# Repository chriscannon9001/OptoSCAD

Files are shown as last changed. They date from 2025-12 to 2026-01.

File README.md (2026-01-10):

# OptoSCAD
Parametric 3d Printable Opto-mechanics.

Plastic is always going to be second-rate for opto-mech, but it actually can do many jobs so long it's not expected to carry a heavy load, or meet interferometer precision.

This project is about opto-mech as fast and cheap as it can reasonably be.

## Installation

Install OpenSCAD, find your libraries folder.

Clone OptoSCAD from git into the libraries folder. Same goes for NopSCADlib (dependency) [https://github.com/nophead/NopSCADlib](https://github.com/nophead/NopSCADlib).

## Hardware Requirements

* 3d Printer
* stock of screws and nuts (e.g. M3, M4, M6)
* stock of springs (e.g. 6x20x.4 mm and 8x20x.8mm)
* (optional) chop saw
* (optional) metal stock, e.g. 6mm dia (for cages) and 12.7mm dia rod or tubes (for posts) 
* (optional) drill press and taps, i.e. if you want to thread solid rod posts (not required)

## Getting started

The folder OptoSCAD/render has some example .stl files you can open in CAD or a slicer just to get a feel for some of the common variants.

See below under Project status to find links to Thingiverse, which offers 3d views of the same rendered .stl files.

Load customizer from OpenSCAD/cust/*.scad to start customizing a design.

***Catalog of (mostly) working mechanics:***

| Customizer |Post|Cage| Notes | Offsite Link |
|---|----|----|---|---|
| cust/Adapter Plates.scad | | | | |
| cust/Adapter Right Angle.scad | | | | |
| cust/Post Holders.scad | X | | untested| [thingiverse](https://www.thingiverse.com/thing:7243131) |
| cust/Post Right Angle Clamp.scad| X | | untested | |
| cust/Cage Plate.scad | X | X | needs work | [thingiverse](https://www.thingiverse.com/thing:7243140) |
| cust/Mirror Mount.scad | X | X | also on HeNe | [thingiverse](https://www.thingiverse.com/thing:7243140) |
| cust/Lens Mount, Focal.scad | | X | untested | |
| cust/Lens Mount, XY.scad | | | in planning | |
| cust/Integrating Sphere.scad | | | unreleased; coming soon | |

## Filaments

***Ranked by creep:***

* PLA (worst)
* PETG
* ASA, ABS
* PC (best)

Coincidentally or not, that's the same as sorting by increasing glass transition temperature Tg.

(Where does PA belong, perhaps between PETG and ASA?)

Some say composite filaments are more stable but my impression is the effect of filament filler is rather weak; PA-CF has higher creep and is also softer than PC.

## Project Status

Bringing every form of opto-mech into the project would be a little ambitious.

I'm working on plans for test beds for benchmarks.

***Planned :***

* Lens Mount
* Integrating Sphere
* Robotics

## Hardware Library

There are other hardware libraries out there already, but OptoSCAD includes its own hardware library. Why do that? OptoSCAD's internal hw lib is aimed at forming negatives (pockets) for trapping nuts, counterboring screws (on the low level side) and forming screw/spring adjuster sets and other things (on the high level side), all with 3d printing in mind. Other libraries are more low-level.

Here is a brief demo snippet.

```
include <OptoSCAD/hw.scad>

$fa=2;
$fs=.2;

// SHC and hex nut with pockets
translate([0, -7, 0]) {
    %neg_hex("M3", 1.0, sink=5, capture=true, minor_access=5);
    vit_hex("M3", 1, TLshaft=8);
}
translate([0, -7, -6]) rotate([180, 0, 0]) {
    %neg_boreSHC("M3", 1.0, sink=3);
    vit_SHC("M3", 1);
}

// spring/screw adjuster with SHC and hex nut
// springspec - ["name", OD, wire, free-length, N-coils, isclosed, isflat, 2nd-OD, color]
spring = ["6x20", 6, .4, 20, 12, 1, 0, 0, "red"];
translate([0, 7, 0]) {
    %neg_adjuster_screwnutspring("M3", spring, l_compressed=6, washer=true, typehead=0, typenut=2, overhead=4);
    vit_adjuster_screwnutspring("M3", spring, l_compressed=6, washer=true, typehead=0, typenut=2);
}
```

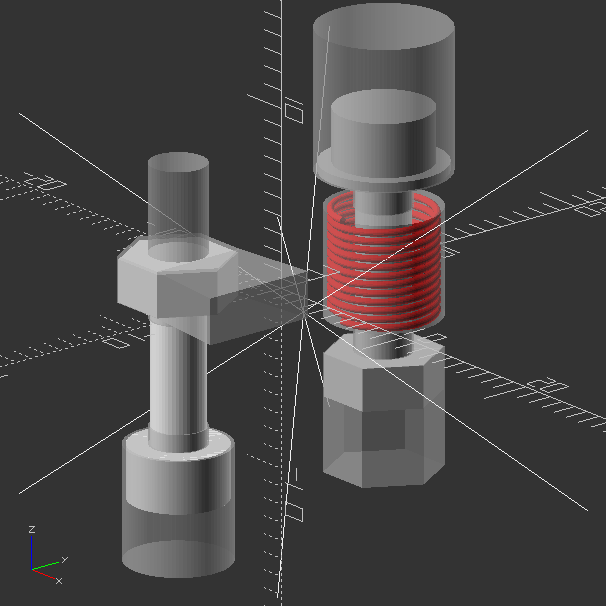
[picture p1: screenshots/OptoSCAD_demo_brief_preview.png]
OptoSCAD demo_brief preview


### More hardware lib demo

Goto the folder OptoSCAD/demo and open of the demo files in OpenSCAD to see demonstrations in more detail. The files hw_pockets.scad and hw_features.scad and hwlookup.scad have additional usage documentation inline.

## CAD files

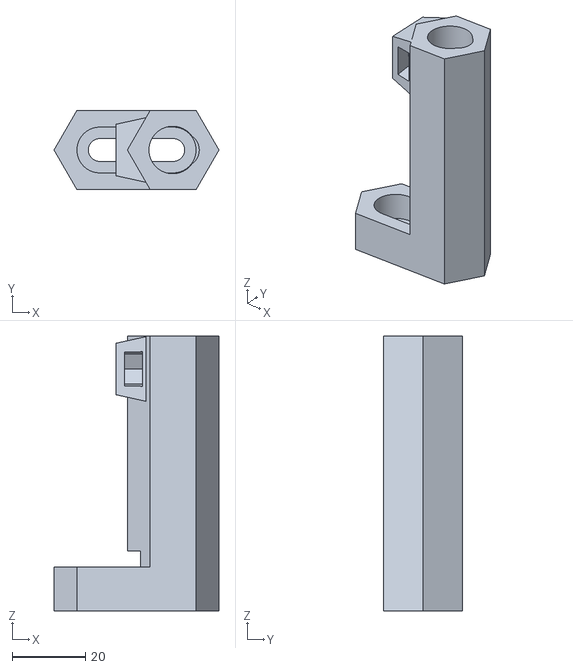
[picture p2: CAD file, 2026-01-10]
render/Post Holders - hexedM6h75id12.7cam20.stl
45.0 x 21.7 x 75.0

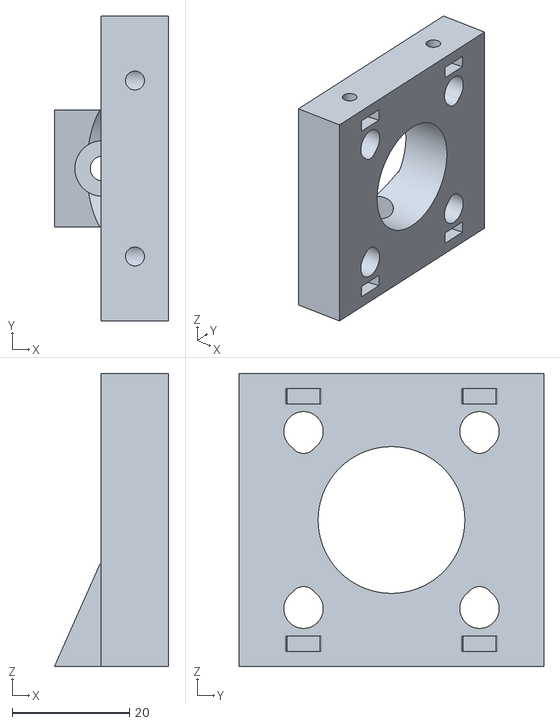
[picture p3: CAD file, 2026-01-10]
render/Cage Plate - cage6x30baseM4.stl
19.5 x 52.0 x 50.0

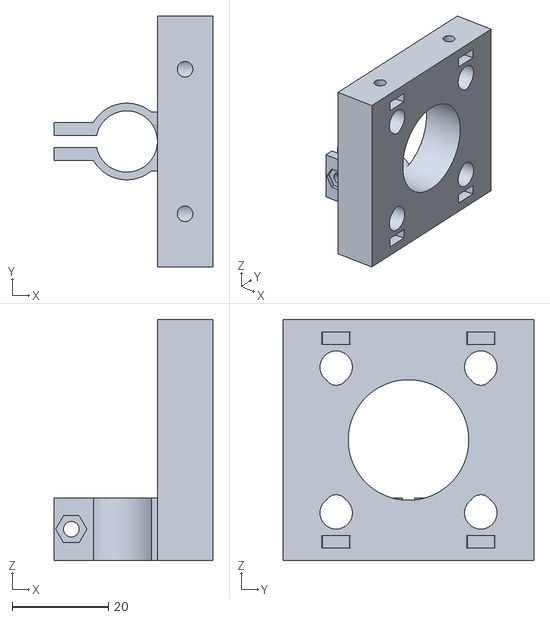
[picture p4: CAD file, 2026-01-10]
render/Cage Plate - cage6x30clamp12.7.stl
32.9 x 52.0 x 50.0

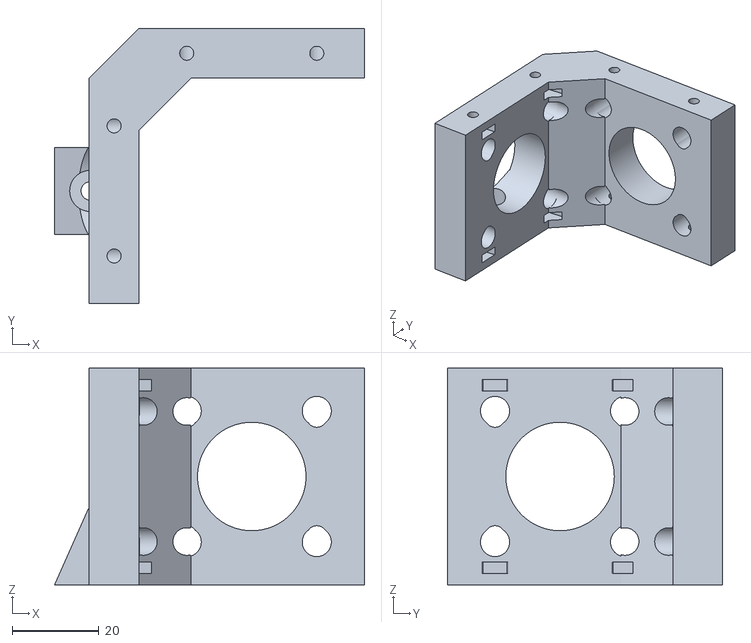
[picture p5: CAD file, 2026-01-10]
render/Cage Plate - cage6x30right90baseM4.stl
71.5 x 63.5 x 50.0

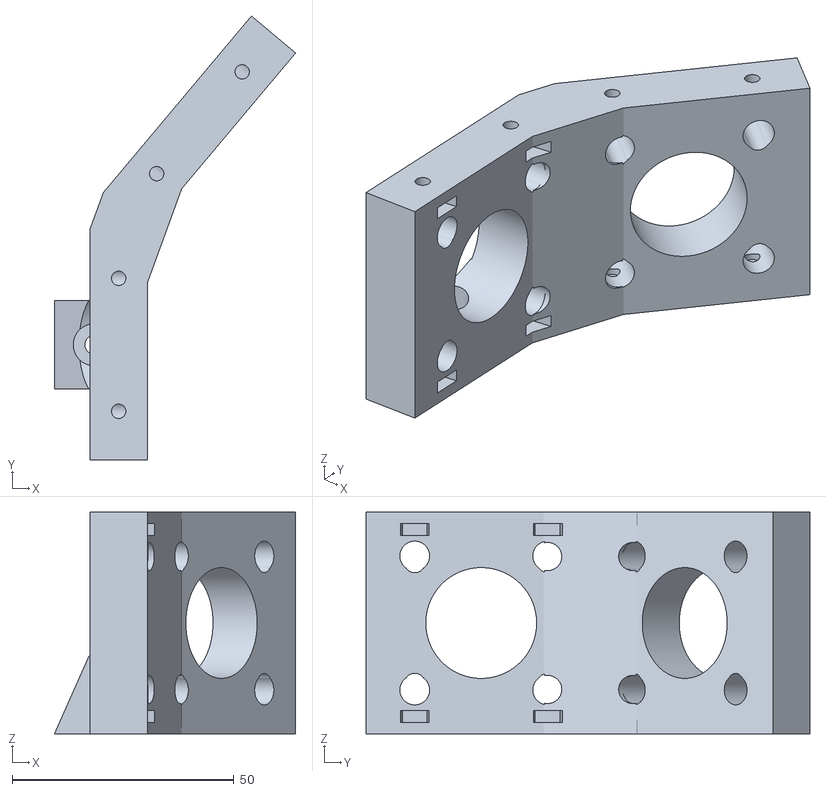
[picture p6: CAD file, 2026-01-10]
render/Cage Plate - cage6x30right140baseM4.stl
54.4 x 100.2 x 50.0

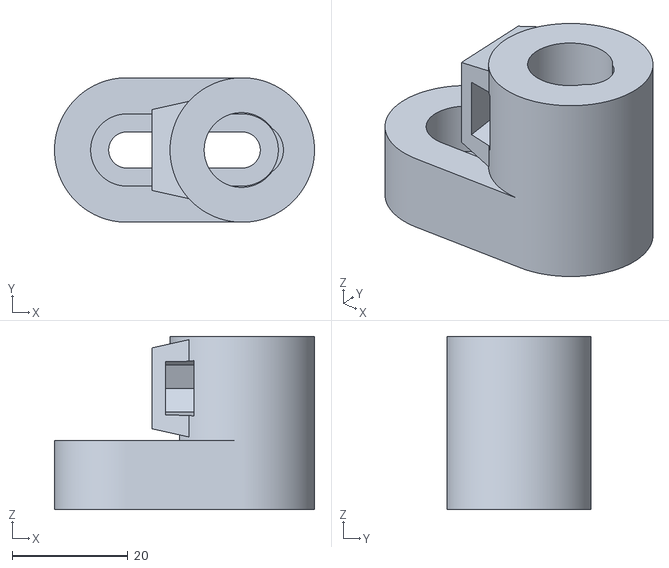
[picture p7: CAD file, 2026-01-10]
render/Post Holders - M6h30id12.7cam20.stl
45.0 x 25.0 x 30.0

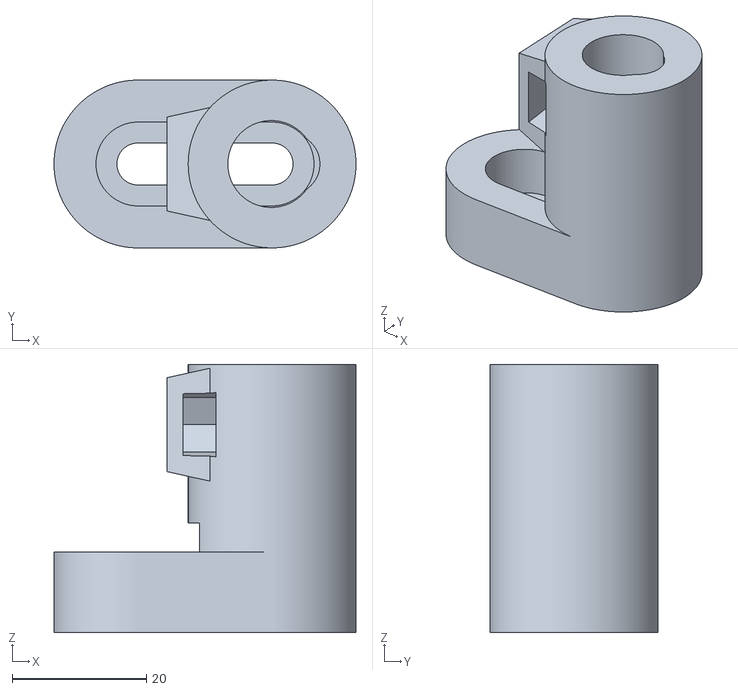
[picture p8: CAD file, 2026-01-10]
render/Post Holders - M6h40id12.7cam20.stl
45.0 x 25.0 x 40.0

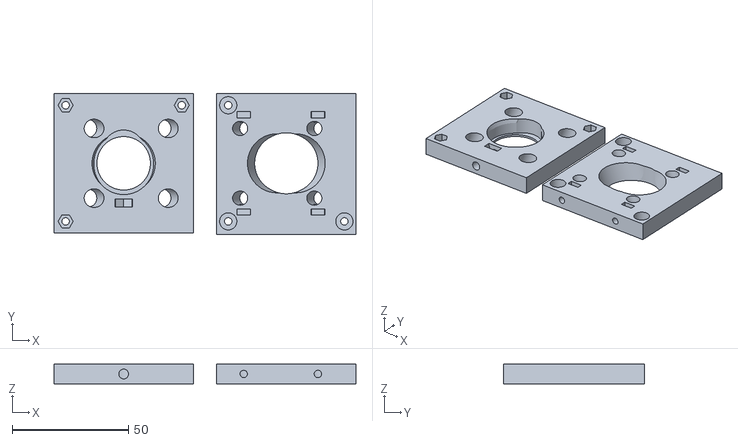
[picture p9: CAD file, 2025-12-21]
render/Mirror Mount - plate60id25.4spring6x20cage6x30aoi20.stl
130.0 x 60.6 x 8.50

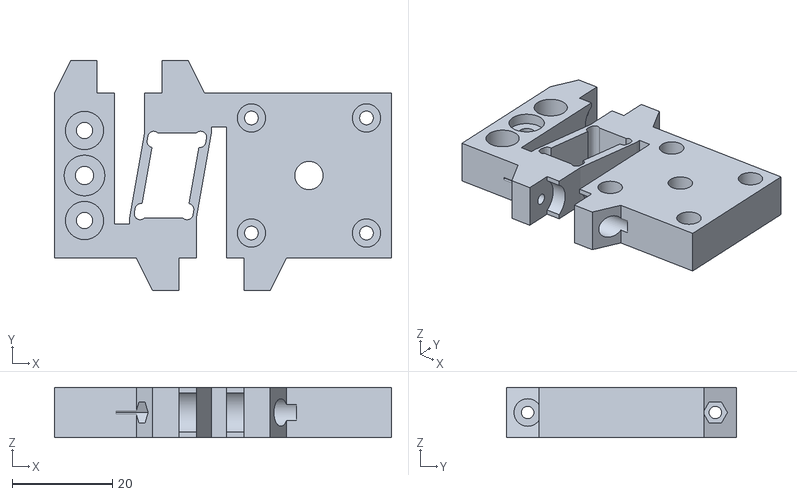
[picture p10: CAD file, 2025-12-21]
render/stepactuator_h10mm_NEMA11_M3.stl
67.4 x 46.0 x 10.0

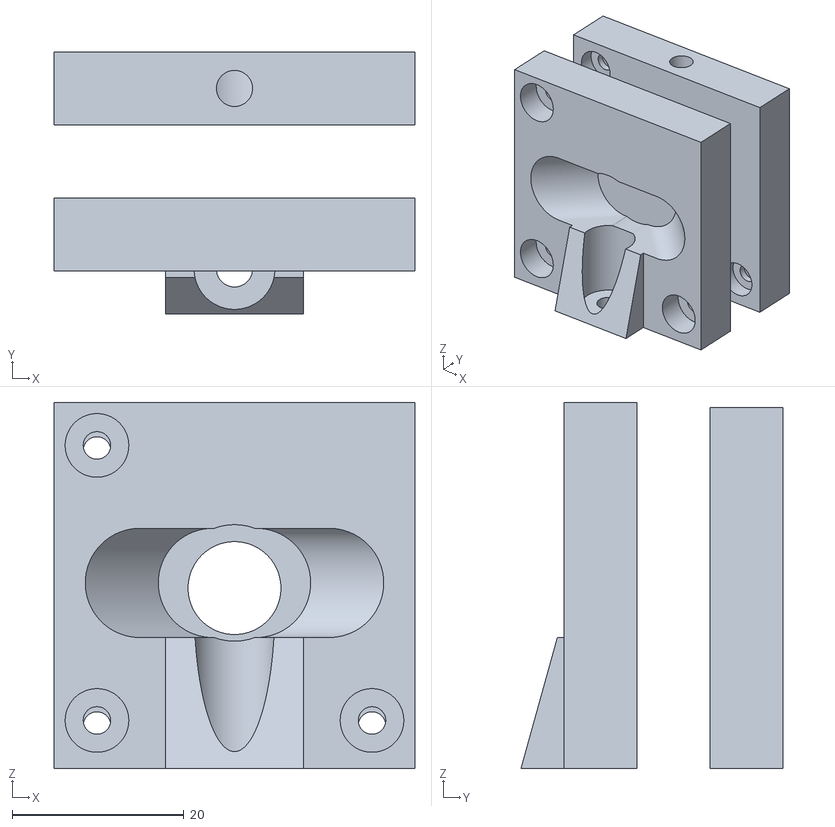
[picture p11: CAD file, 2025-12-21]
render/Mirror Mount - leftplate42id12.7spring6x20baseM4.stl
42.0 x 30.5 x 42.6

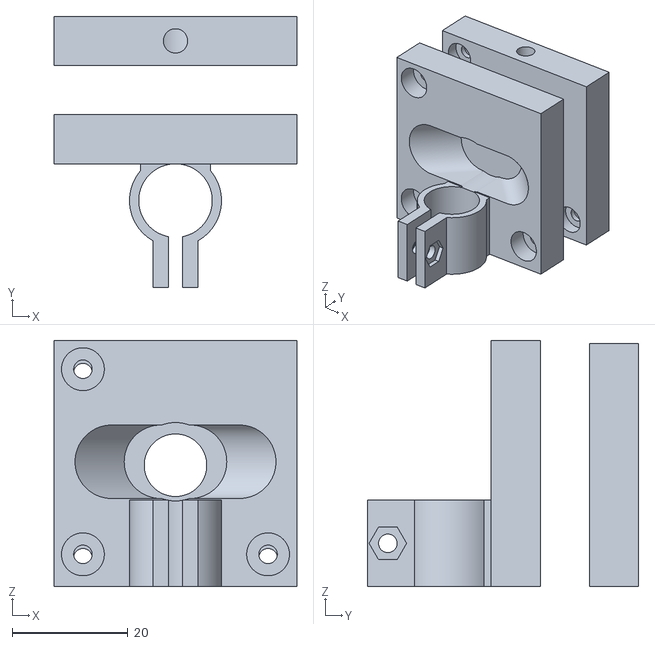
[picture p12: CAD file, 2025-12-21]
render/Mirror Mount - leftplate42id12.7spring6x20clamp12.7.stl
42.0 x 46.9 x 42.6

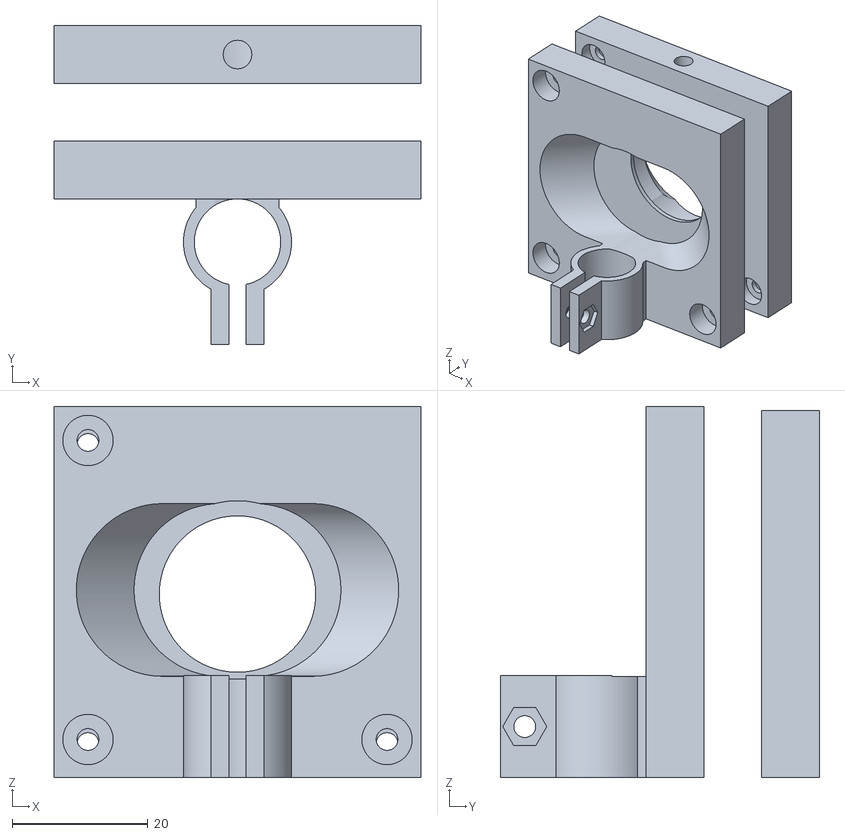
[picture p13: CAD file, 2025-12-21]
render/Mirror Mount - leftplate52id25.4spring6x20clamp12.7.stl
54.0 x 46.9 x 54.6

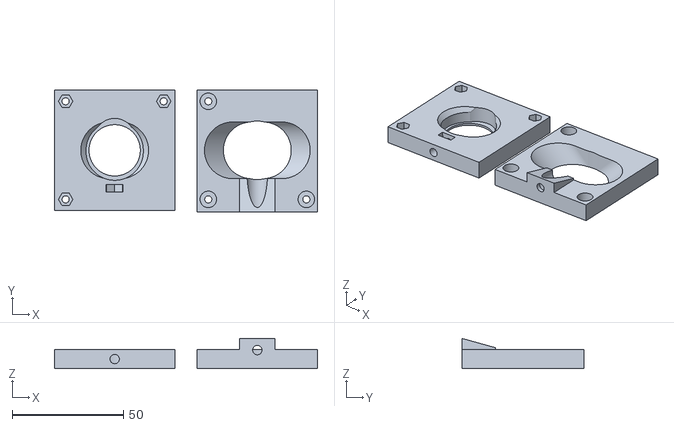
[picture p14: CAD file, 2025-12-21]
render/Mirror Mount - leftplate52id25.4spring6x20baseM4.stl
118.0 x 54.6 x 13.5

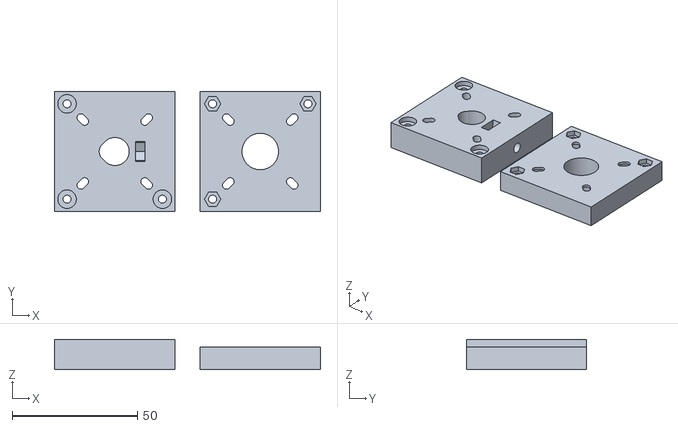
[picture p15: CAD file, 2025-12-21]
render/Mirror Mount, HeNe to 11odcollimator.stl
106.0 x 48.0 x 12.0

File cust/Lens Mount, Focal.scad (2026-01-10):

/* 'Lens Mount, Focal'
 * A lens mount with precision focal adjuster.
 *
 * Authors:
 * Chris Cannon
 */

use <../hw_pockets.scad>
use <../hw_features.scad>
use <../flexure.scad>

vitamins = true;

// [snug, close, loose, gap]
margins = [.06, .12, .24, .35];

/* [Cage Plate] */

Cage_setscrew = "M3";

Cage_nuttype = 2; //[2: hex, 3: square, 4: tapped]

D_plate1 = 44;

L_plate1 = 50;

T_plate1 = 11.5;

// [rod, oncenter, AOI]
Cage_rods = [6.35, 30, 0];

/* [Mirror Plate] */

D_plate2 = 20;

L_plate2 = 30;

T_plate2 = 9.5;

// Mirror diameter, mm
Diameter = 12.7;

// Mirror diameter tolerance +/-, mm
Dia_tol = .3;

// Inner-diameter, thickness of flange, mm
Flange = [10.8, 1];

// Size of setscrew
Setscrew_size = "M4";

Setscrew_type = 2; //[2: hex, 3: square, 4: tapped]

// Offset (mm) from mirror opening to nut for setscrew
Setscrew_nutoffset = 2.5;

// rotation around y-axis where setscrew is attached
Setscrew_position = 90;

/* [Flexure] */

// [Length, Width, Depth, Gap]
Flex = [22, 16, 12, 2.9];

// total length of flex
L_flexTL = 36;

rh_flex = true;

/* [Actuator] */
Screw_dz = "M3";

Supportthick_dz = 3;

Nuttype_dz = 2; //[2: hex, 3: square, 4: tapped]

// springspec - ["name", OD, wire, free-length, N-coils, isclosed, isflat, 2nd-OD, color]
Spring_spec = ["8x20", 8, .8, 20, 4.8, 1, 0, 0, "red"];

compressedLength = 10;

Actuator_inset = 5;

module _end_cust_() {}

$fa = $preview? 5 : 1;
$fs = $preview? .4 : .1;

span = Flex[1] + 2*Flex[3];
s = rh_flex? 1 : -1;

module coord_actuator() {
    x = (span - compressedLength) / 2;
    y = -L_plate1/2 + Actuator_inset;
    z = Flex[2]/2;
    translate([x, s*y, z])
    rotate([0, 90, 0])
    rotate(-s*90)
    children();
}

difference() {
    union() {
        // plate1
        translate([span/2+T_plate1/2, 0])
        linear_extrude(D_plate1+Flex[2])
        square([T_plate1, L_plate1], center=true);
        // plate2
        D2 = D_plate1/2+D_plate2/2;
        translate([-span/2-T_plate2/2, 0]) {
            linear_extrude(D2+Flex[2])
            square([T_plate2, L_plate2], center=true);
            // plate2b
            linear_extrude(Flex[2])
            square([T_plate2, L_plate1], center=true);
        }
        // backing for the adjuster
        linear_extrude(Flex[2])
        polygon([[-span/2, -s*L_plate1/2],
            [span/2-compressedLength, -s*L_plate1/2],
            [span/2-compressedLength, -s*L_flexTL/2],
            [-span/2, -s*L_flexTL/2]]);
        // flexure
        thick3 = (L_flexTL - Flex[0])/2;
        flexure_translation1(Flex[0], Flex[1], Flex[2], thick1=0.8, thick2=2, thick3=thick3, bias=0);
        // connect flexure across the gap
        for (j = [-1,1]) {
            y = j*s*(Flex[0]/2+thick3/2+.25);
            x = j*(Flex[1]/2+Flex[3]/2);
            translate([x, y])
            linear_extrude(Flex[2])
            square([Flex[3], thick3-.5], center=true);
        }
    }
    // mirror cutout
    diag = sqrt(D_plate2^2+L_plate2^2);
    translate([-span/2, 0, D_plate1/2+Flex[2]])
    rotate([0, -90, 0])
    neg_shaftsetscrew(diag, T_plate2, Diameter, Dia_tol, Flange, Setscrew_size, Setscrew_type, Setscrew_nutoffset, Setscrew_position, margins=margins);
    // cage rod pockets
    translate([span/2+T_plate1+.05, 0, D_plate1/2+Flex[2]])
    rotate([0, -90, 0]) {
        rad_ss = (D_plate1 - Cage_rods[1])/2 + 1;
        neg_cage1(Cage_rods[0], Cage_rods[1], T_plate1+.1, Cage_setscrew, rad_ss, ss_angle=-1,  ss_nut_type=Cage_nuttype, AOI=Cage_rods[2], margins=margins, fast=$preview, overhead=span+T_plate2, overbore=2*margins[3]);
        cylinder(h=T_plate1+.1, d=Diameter);
    }
    // actuator pockets
    coord_actuator()
    neg_adjuster_screwnutspring(Screw_dz, Spring_spec, typehead=0, typenut=Nuttype_dz, washer=true, l_compressed=compressedLength, support_thick=Supportthick_dz, access_length=10, overhead=10, margins=margins);
}

if (vitamins) {
    coord_actuator()
    vit_adjuster_screwnutspring(Screw_dz, Spring_spec, typehead=0, typenut=2, washer=true,  l_compressed=compressedLength, support_thick=Supportthick_dz);
}

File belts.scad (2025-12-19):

// Terminology:
// L - distance between pulley centers
// Cb - total Circumference of belt
// d1, d2 - diameters of pulleys
// C1, C2 - Circumferences of pulleys
// pitch - pitch from tooth to tooth
// Tb - number of teeth of belt
// T1, T2 - number of teeth of pulleys
// alpha - angle (degrees)
// beltspec - [L, pitch, Tb, T1, T2, alpha]

// an intermediate
function d0(Cb, d1, d2) = 4*Cb-2*PI*(d1+d2);

// lower level - returns the distance between pulley axles
function L_pulley_d0(d0, d1, d2) = (d0 + sqrt(d0^2 - 32*(d1-d2)^2))/16;

// returns L, the distance between pulleys
function L_pulley(Cb, d1, d2) = L_pulley_d0(d0(Cb, d1, d2), d1, d2);

// return Cb, the length of the belt
function Cb_pulley(L, d1, d2) = 2*L + PI*(d1+d2)/2 + (d1-d2)^2/(4*L);

function alpha(L, d1, d2) = asin((d1-d2)/L/2);

// round a up to the nearest mod
function next_up(a, mod) = mod*ceil(a/mod);

function Tb_nearest_belt(T1, T2, L, pitch, nearest=2) = next_up(Cb_pulley(L/pitch, T1/PI, T2/PI), nearest);

// beltspec - [L, pitch, Tb, T1, T2, alpha]
function beltspec1(T1, T2, L, pitch) = [L, pitch, Cb_pulley(L, T1/PI, T2/PI)/pitch, T1, T2, alpha(L/pitch, T1/PI, T2/PI)];

function beltspec2(T1, T2, Tb, pitch) = [pitch*L_pulley(Tb, T1/PI, T2/PI), pitch, Tb, T1, T2, alpha(L_pulley(Tb, T1/PI, T2/PI), T1/PI, T2/PI)];

// returns beltspec with Tb rounded up and L to match
function beltspec_nearest(T1, T2, L, pitch, nearest=2) = beltspec2(T1, T2, Tb_nearest_belt(T1, T2, L, pitch, nearest=nearest), pitch);

// similar to circle, but limits angular extent between a1 to a2 (degrees)
module arc(r, a1, a2) {
    del_a = abs(a2 - a1);
    // points carries a triangle wedge with a low polygon circle between arms
    points = [[0,0], for (i=[0:6]) [r*1.5*cos(a1 + i*del_a/6),r*1.5*sin(a1 + i*del_a/6)]];
    intersection() {
        polygon(points);
        circle(r);
    }
}

// form a 2d sketch of the belt
module belt_2d(beltspec, thick) {
    L = beltspec[0];
    pitch = beltspec[1];
    Tb = beltspec[2];
    T1 = beltspec[3];
    T2 = beltspec[4];
    alpha = beltspec[5];
    r1 = T1*pitch/PI/2;
    r2 = T2*pitch/PI/2;
    a11 = 90-alpha;
    a12 = 270+alpha;
    a21 = -90+alpha;
    a22 = 90-alpha;
    d = sqrt(L^2 - (r2-r1)^2);
    // belt around gear1
    difference() {
        arc(r1+thick, 90-alpha, 270+alpha);
        circle(r1);
    }
    // belt around pulley2
    translate([L, 0, 0]) difference() {
        arc(r2+thick, -90+alpha, 90-alpha);
        circle(r2);
    }
    // belt along top straight
    x = r1*cos(a11);
    y = r1*sin(a11);
    translate([x, y, 0]) rotate([0, 0, -alpha]) square([d, thick]);
    // belt along bottom straight
    x2 = (r1+thick)*cos(a12);
    y2 = (r1+thick)*sin(a12);
    translate([x2, y2, 0]) rotate([0, 0, alpha]) square([d, thick]);
}

// a little demo
spec = beltspec_nearest(50, 20, 35, 2, nearest=2);
echo(spec);
linear_extrude(6) belt_2d(spec, 2);

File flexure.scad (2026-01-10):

//use <./hw_mates.scad>
use <./hw_features.scad>
use <./util.scad>

module slot(h, r, x1, y1, x2, y2) {
    hull() {
        translate([x1, y1, 0]) cylinder(h=h, r=r);
        translate([x2, y2, 0]) cylinder(h=h, r=r);
    }
}

module flexure_rotation1(length, width, height, n_spans, uncut_length=2, thick=0.8, vgap=0.2, fillet=0.4) {
    // flexure_rotation1 is a pair of webs that span front and
    // back plates. From the top, the cross-section of the webs
    // is an X, but the spans of the two webs don't intersect.
    // This is a classic rotation flexure, with high stiffness
    // the other 5 axes.
    // Coordinates w.r.t. center bottom, as with cylinder module
    //
    // length: mm, gap in y between front, back plates
    // width: mm, width in x of front, back plates
    // height: mm, height in z of module
    // n_spans: int, number of spans per web from plate to plate
    // uncut_length: mm, each web needs an amount of diag length not cut into spans
    // thick: mm, default 0.8, thickness of spans, normally 2x nozzle diameter
    // vgap: mm, default 0.2, need a gap between spans so they don't fuse
    // fillet: mm, radius of fillet on inside corner of spans
    length2 = length + thick/1.414;
    width2 = width - thick/1.414;
    theta = atan(length2/width2);
    diag = sqrt(length2^2 + width2^2);
    cut_len = diag - uncut_length*2;
    dy = height/(n_spans*2);
    // front and back bases
    translate([0, length/2+thick/2, height/2])
        cube([width, thick, height], center=true);
    translate([0, -length/2-thick/2, height/2])
        cube([width, thick, height], center=true);
    // even flexes
    rotate([0, 0, theta])
        difference() {
            translate([0, 0, height/2]) cube([diag, thick, height], center=true);
            for (i = [1:n_spans]) {
                y = dy * (i * 2 -.5);
                translate([0, 0, y]) cube([cut_len, thick+1, dy+vgap*2], center=true);
            }
        }
    // odd flexes
    rotate([0, 0, -theta])
        difference() {
            translate([0, 0, height/2]) cube([diag, thick, height], center=true);
            for (i = [1:n_spans+.5]) {
                y = dy * (i * 2 - 1.5);
                translate([0, 0, y]) cube([cut_len, thick+1, dy+vgap*2], center=true);
            }
        }
    // fillet
    angle = theta/2;
    y = length/2;
    x = width/2 - thick/sin(theta);
    translate([x, y, 0]) rotate([0, 0, angle])
        filletsingle(fillet, height, angle=angle*2);
    translate([-x, y, 0]) rotate([0, 0, 180-angle])
        filletsingle(fillet, height, angle=angle*2);
    translate([x, -y, 0]) rotate([0, 0, -angle])
        filletsingle(fillet, height, angle=angle*2);
    translate([-x, -y, 0]) rotate([0, 0, 180+angle])
        filletsingle(fillet, height, angle=angle*2);
}

module flexure_rotation2(length, width, height, n_spans, uncut_length=2, thick=0.8, vgap=0.2, fillet=0.4) {
    length2 = length + thick/1.414;
    width2 = width - thick/1.414;
    theta = atan(length2/width2);
    diag = sqrt(length2^2 + width2^2);
    cut_len = diag - uncut_length*2;
    dy = height/(n_spans*2);
    // front and back bases
    translate([0, length/2+thick/2, height/2])
        cube([width, thick, height], center=true);
    translate([0, -length/2-thick/2, height/2])
        cube([width, thick, height], center=true);
}

module flexure_translation1(length, width, height, thick1=0.8, thick2=2, thick3=5, bias=0) {
    // flexure_translation1 is the simplest 2-leaf translation flexure
    // This is a classic translation flexure, with high stiffness
    // the other 5 axes.
    // coordinates w.r.t. center bottom, as with cylinder module
    //
    // length: mm, gap in y between front, back plates
    // width: mm, width in x of front, back plates
    // height: mm, height in z of module
    // thick1: mm, default 0.8, thickness of leafs at their thinnest, normally 2x nozzle diameter
    // thick2: mm, default 2, thickness of leafs at their max
    // thick3: mm, default 5, thickness of ground, floating bases
    // bias: mm, default 0, top and bottom are shifted by this amount (clockwise)
    radius = thick2 - thick1;
    slope = 2*bias/length;
    difference() {
        union() {
            // bottom base
            translate([-width/2-bias, -length/2-thick3, 0]) cube([width, thick3, height]);
            // top base
            translate([-width/2+bias, length/2, 0]) cube([width, thick3, height]);
            // left side with slope (bias)
            translate([-width/2, 0, 0]) linear_extrude(height) polygon([[-bias, -length/2], [thick2-bias, -length/2], [thick2+bias, length/2], [bias, length/2]]);
            // right side with slope (bias)
            translate([width/2, 0, 0]) linear_extrude(height) polygon([[-bias, -length/2], [-thick2-bias, -length/2], [-thick2+bias, length/2], [bias, length/2]]);
        }
        dl = 1.1*thick1;
        for (s = [-1, 1]) {
            y1 = s*(.7*radius - length/2);
            y2 = y1 + s*dl;
            dx1 = y1 * slope;
            dx2 = y2 * slope;
            translate([0, 0, -.001]) slot(height+.002, radius, dx1-width/2+thick2, y1, dx2-width/2+thick2, y2);
            translate([0, 0, -.001]) slot(height+.002, radius, dx1+width/2-thick2, y1, dx2+width/2-thick2, y2);
        }
    }
}

module flexure_translation2(length, width, height, gap1=2, gap2=1, thick1=0.8, thick2=2., thick3=5) {
    // flexure_translation2 is a 4-leaf translation flexure
    // This is a classic translation flexure, with high stiffness
    // the other 5 axes.
    // Coordinates are w.r.t. the floating base
    //
    // length: mm, gap in y between front, back plates
    // width: mm, width in x of front, back plates
    // height: mm, height in z of module
    // gap1: mm, gap allowing movement
    // gap2: mm, air gap between floating and ground
    // thick1: mm, default 0.8, thickness of leafs at their thinnest, normally 2x nozzle diameter
    // thick2: mm, default 2, thickness of leafs at their max
    // thick3: mm, default 6, thickness of ground, floating bases
    radius = thick2 - thick1;
    width_g = width - 2*(thick1 + radius*2 + gap1);
    length2 = length - thick3 - gap2;
    difference() {
        union() {
            // ground platform
            translate([-width_g/2, -thick3, 0]) cube([width_g, thick3, height]);
            // moving platform
            translate([-width/2, -thick3*2-gap2, 0]) cube([width, thick3, height]);
            // floating platform
            translate([-width/2, length2, 0]) cube([width, thick3, height]);
            // leafs
            translate([(width-thick2)/2, (length2-thick3-gap2)/2, height/2]) cube([thick2, length, height], center=true);
            translate([-(width-thick2)/2, (length2-thick3-gap2)/2, height/2]) cube([thick2, length, height], center=true);
            translate([-(width_g-thick2)/2, length2/2, height/2]) cube([thick2, length2, height], center=true);
            translate([(width_g-thick2)/2, length2/2, height/2]) cube([thick2, length2, height], center=true);
            // fillets
            translate([width_g/2, length2, -.001]) rotate([0, 0, 135]) filletsingle(radius, height+.002, angle=90);
            translate([-width_g/2, length2, -.001]) rotate([0, 0, 45]) filletsingle(radius, height+.002, angle=90);
        }
        // remove cylinders to make flex lines
        translate([-width_g/2+radius+thick1, 0, -.001]) cylinder(h=height+.002, r=radius);
        translate([width_g/2-radius-thick1, 0, -.001]) cylinder(h=height+.002, r=radius);
        translate([-width/2+radius+thick1, 0, -.001]) cylinder(h=height+.002, r=radius);
        translate([width/2-radius-thick1, 0, -.001]) cylinder(h=height+.002, r=radius);
        translate([-width_g/2+radius+thick1, length2-radius, -.001]) cylinder(h=height+.002, r=radius);
        translate([width_g/2-radius-thick1, length2-radius, -.001]) cylinder(h=height+.002, r=radius);
        translate([width/2-radius-thick1, length2-radius, -.001]) cylinder(h=height+.002, r=radius);
        translate([-width/2+radius+thick1, length2-radius, -.001]) cylinder(h=height+.002, r=radius);
    }
}

module adjuster_alongside_neg(screwsize, springspec, H, W, l_compressed, support_thick=2, decenter=0) {
    translate([0, W/2+decenter, H/2]) rotate([0, 90, 0]) rotate([0, 0, 90]) neg_adjuster_screwnutspring(screwsize, springspec, l_compressed=l_compressed, support_thick=support_thick, overhead=W+support_thick);
}

module adjuster_alongside(screwsize, springspec, H, W, l_compressed, support_thick=2, decenter=0) {
    x1 = l_compressed/2;
    x2 = x1 + support_thick + W/2;
    x3 = x2 + W/2;
    difference() {
        union() for (s = [-1, 1]) {
            linear_extrude(H) polygon([[s*x1, 0], [s*x1, W], [s*x2, W], [s*x3, 0]]);
        }
        adjuster_alongside_neg(screwsize, springspec, H, W, l_compressed, support_thick=support_thick, decenter=decenter);
    }
}
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

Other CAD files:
render/Mirror Mount - plate60id25.4spring6x20cage6x30aoi0.stl
hw.scad
cust/Adapter Plates.scad
cust/Adapter Right Angle.scad
cust/Cage Plate.scad
cust/Mirror Mount.scad
cust/Post Holders.scad
cust/Post Right Angle Clamp.scad
cust/Pulley Maker.scad
demo/demo_brief.scad
demo/demo_hw_features.scad
demo/demo_hw_pockets.scad
demo/demo_hw_pockets_old.scad
hw_features.scad
hw_pockets.scad
hwlookup.scad
pulleys.scad
util.scad

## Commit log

2025-12-19 First commit.
    [Adapter Plates.scad, Adapter Right Angle.scad, Cage Plate.scad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]
2025-12-21 Improved readme, include rendered .stl files.
    [Cage Plate - cage6x30baseM4.stl, Cage Plate - cage6x30cage12.7.stl, Cage Plate - cage6x30right160baseM4.stl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]
2025-12-21 hw_mates.scad is depreciated
    [hw_mates.scad]
2026-01-02 Revisions, Additions
    [Lens Mount, Focal.scad, Post Holders - M6h30id12.7cam20.stl, Post Holders - M6h40id12.7cam20.stl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]
2026-01-04 Minor revisions.
    [Cage Plate - cage6x30clamp12.7.stl, Lens Mount, Focal.scad, Mirror Mount.scad]
2026-01-10 Adjustments to defaults. Improvement to neg_cage1 bore definition.
    [Adapter Plates.scad, Adapter Right Angle.scad, Cage Plate - cage6x30baseM4.stl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]
